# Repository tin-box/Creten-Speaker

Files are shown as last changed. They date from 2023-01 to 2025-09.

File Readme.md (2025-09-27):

<h1>Creten Bluetooth Speaker Project</h1>
<h2>Purpose</h2>
This is a fun project inspired by [DIY Perks] (https://www.youtube.com/@DIYPerks) on YouTube.  Instead of using carpentry, I elected to draw the project in CAD and 3D print the concrete form and most of the components.  I used PLA for the form and a high durometer TPU for speaker components. 
I also modified his design using a square port on the top to mount controls and other items vs his elongated port.  This change allows the concrete to flow into the space below the port more easily so that less water is required in the concrete mix which makes the housing stronger once cured.

This has been a fun hobby project and I hope sharing these 3D print STL files will allow other hobbyists to experiment and try out the appoach. 

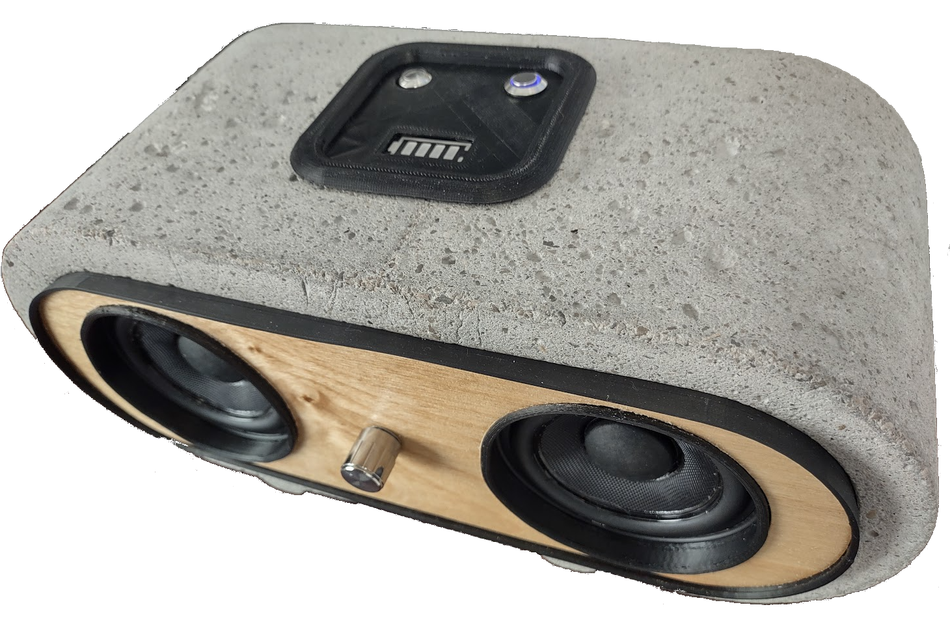
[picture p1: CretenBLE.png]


<h2>Instructions</h2>
The included STL models were created with Fusion360 using the free maker edition. 
The parts were all printed on a printer with 300mm x 300mm bed. 

The form built in halves, both to allow the final product to be larger than the printer bed allows as well as to make it so the form can be removed from the housing once the concrete has cured.
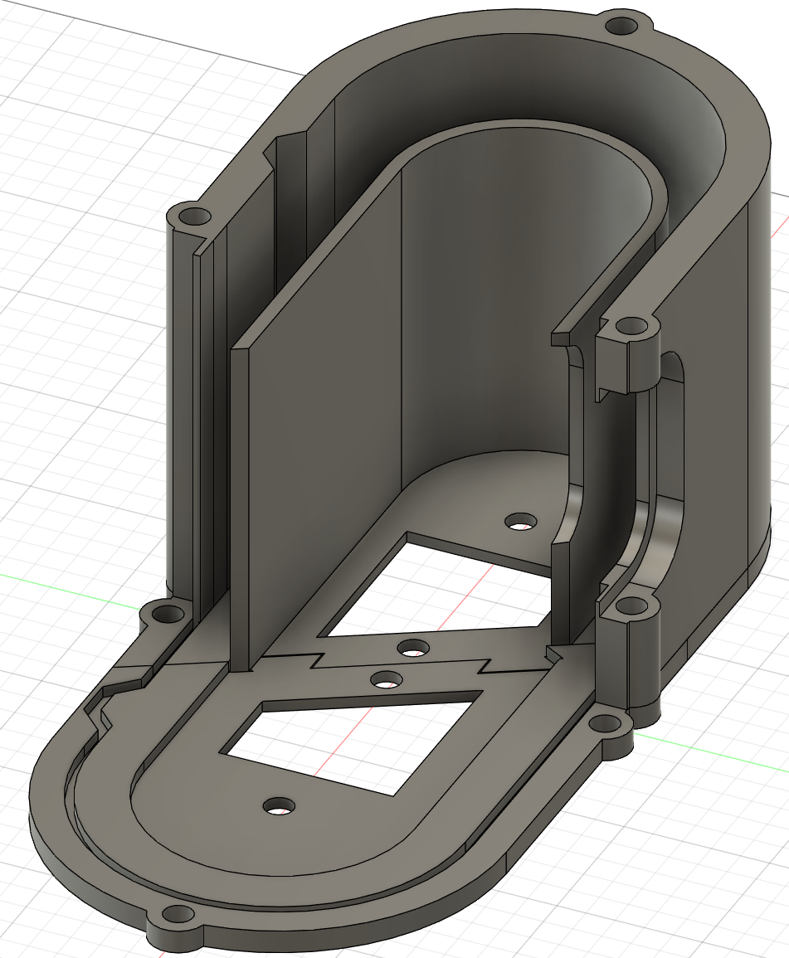
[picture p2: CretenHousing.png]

The Bottom Plate models are the first to print with the inner and outer shells mounting to the Bottom plates.  They all have a tongue and groove design that keeps everything from deforming with the weight of the concrete and also prevents the concrete from leaking, if you use vibration to remove air bubble from the mix.  

The Pins hold all of the forms together and allow the form to be dissassembled once the concreete cures. 

The Speaker mount, Speaker Rings, Control Panel and USB plug are all printed from TPU.  3" Dayton Audio speakers were purchased from Dayton Audio and 50W BLE amplifier board purchased on Amazon. 

<h2>Finishing</h2>
After the concrete cured I cleaned up the housing by sanding it with 80grit sand paper with a water slurry.  This cleaned up the edges and exposed the aggregate on the surfaces.  The Speaker mount assembly is a press fit.  There is a speaker mount pattern that I used to cut out a thin piece of plywood that give the front an warm accent and hides the speaker fasteners. The Speaker mount and speaker rings have a lip in the design that holds the wood insert.  Installing the wood insert is tight and requires a technique similar to mounting a tire on a rim.  

I used USB-C type charge port interface in the printed grommet.  This was connected to a Battery Management PCB board for a 3S or 4S configuration that is wired to an on/off switch and mattery level indicator.  There is a momentary switch type button in the battery level indicator circuit that power the level indicator when pressed.   I used Lithium Ion 13650 batteries from disassembled old laptop batteries.  in a 3 battery configuration it gives me 8 hours of runtime. 

I know the instructions are sparse, but its a hobby project you should modify the materials to your own design and have fun figuring it out.

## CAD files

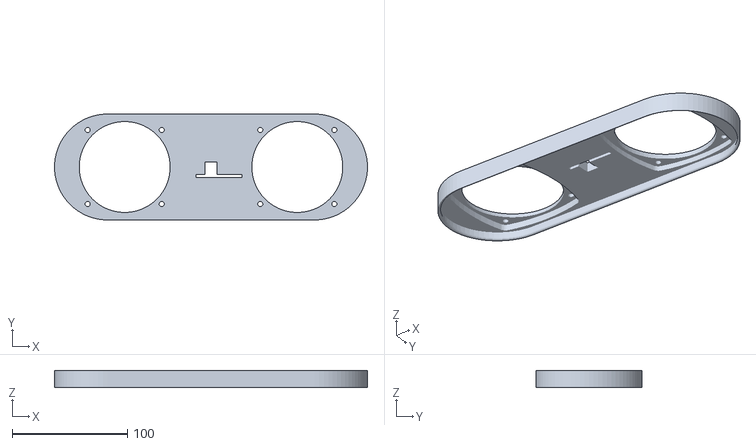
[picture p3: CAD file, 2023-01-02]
V4_3InchMountThin3mmV2.stl
272.0 x 92.0 x 15.0

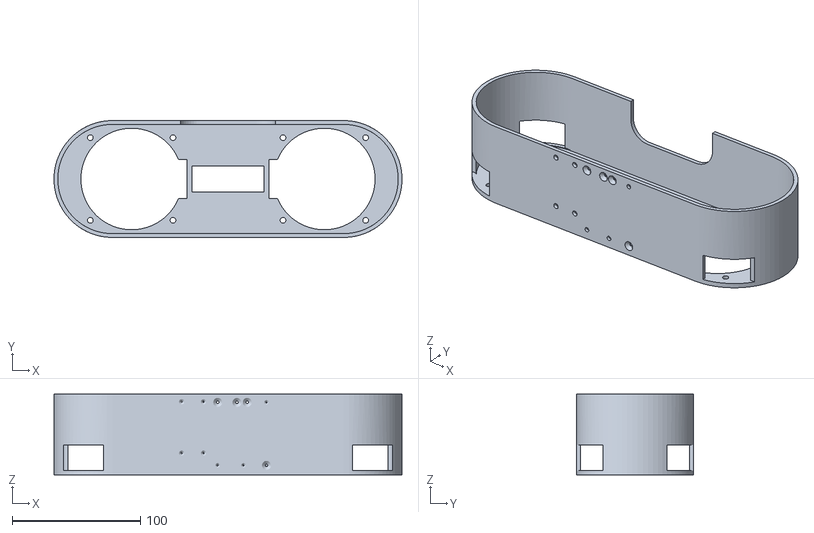
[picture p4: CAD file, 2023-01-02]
V4_MountSupportv2.stl
270.9 x 91.0 x 63.0

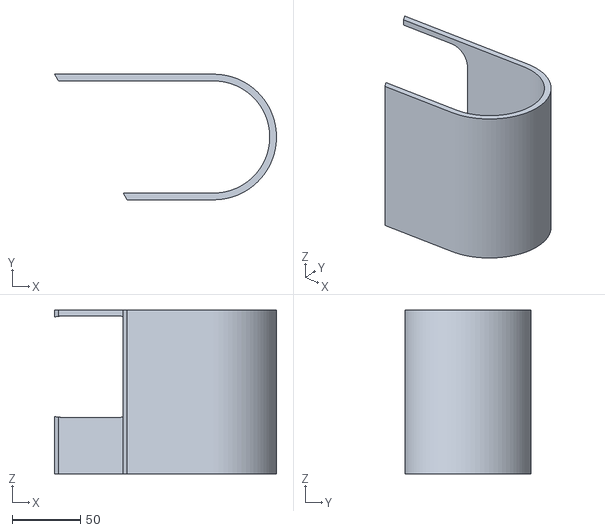
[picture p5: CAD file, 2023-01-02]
V4_InnerHalfNoBottom_R.stl
162.5 x 92.0 x 120.0

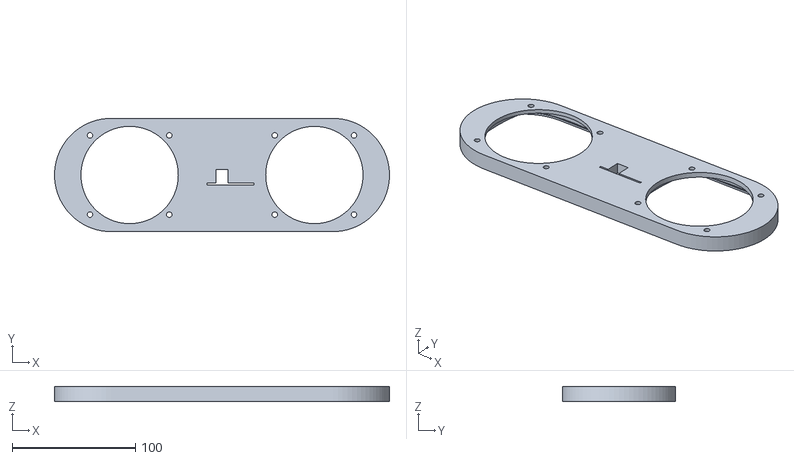
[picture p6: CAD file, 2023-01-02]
V4_3InchMountThin.stl
272.0 x 92.0 x 12.0

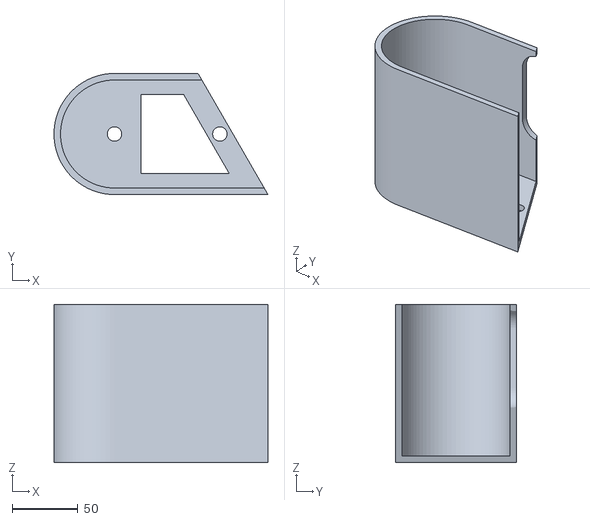
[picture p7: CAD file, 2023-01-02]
V4_InnerHalf_L.stl
162.5 x 92.0 x 120.0

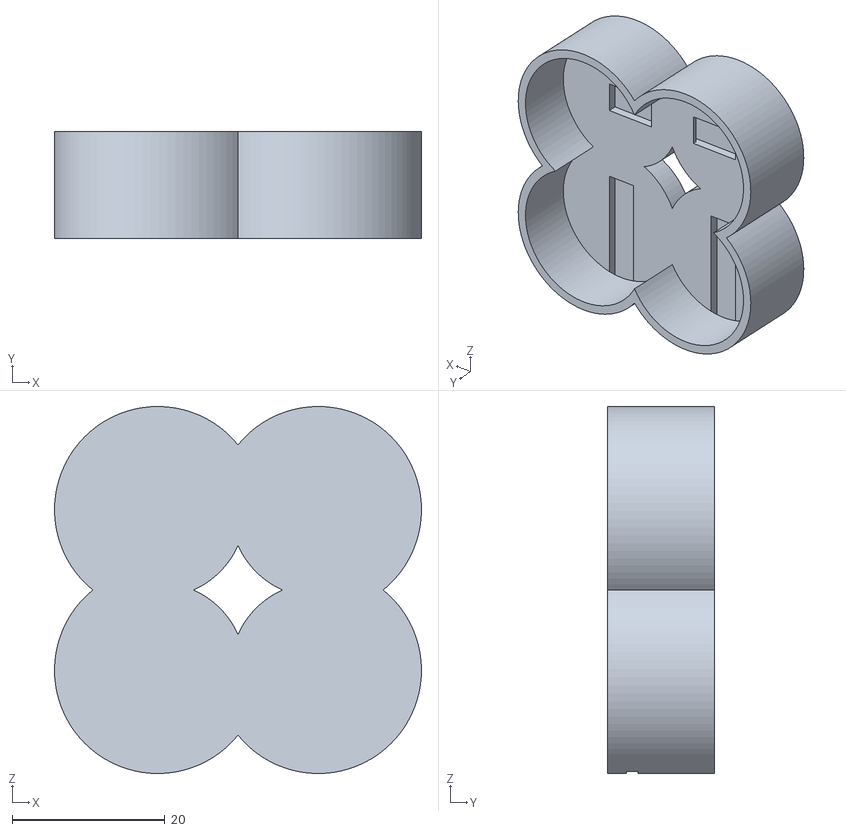
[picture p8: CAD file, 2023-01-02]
QuadBaseCap_Bridge.stl
48.0 x 14.0 x 48.0

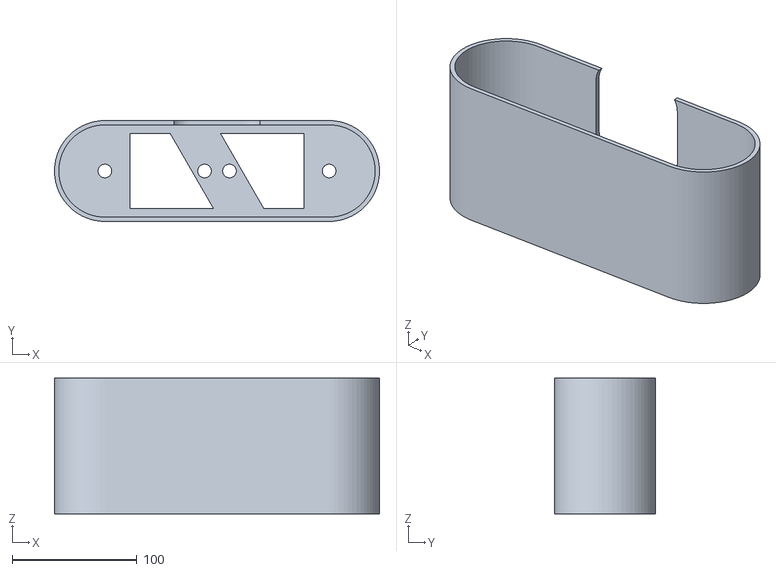
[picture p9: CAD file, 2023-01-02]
V4_LinerForNoBottom.stl
260.9 x 81.0 x 109.0

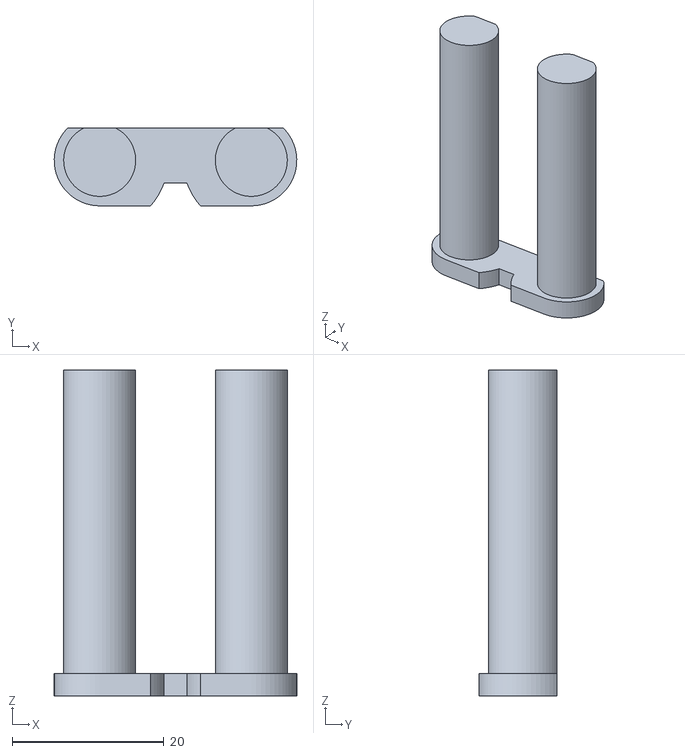
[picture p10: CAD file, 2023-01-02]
Bottom_Short_Pin.stl
32.0 x 10.2 x 43.0

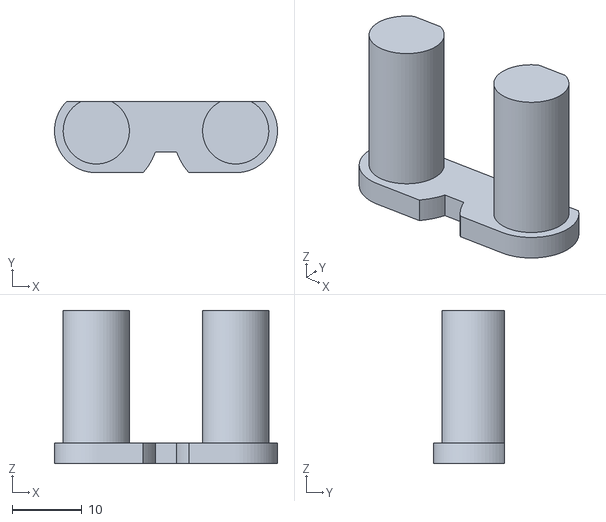
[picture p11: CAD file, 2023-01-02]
Top_Short_Pin.stl
32.0 x 10.2 x 22.0

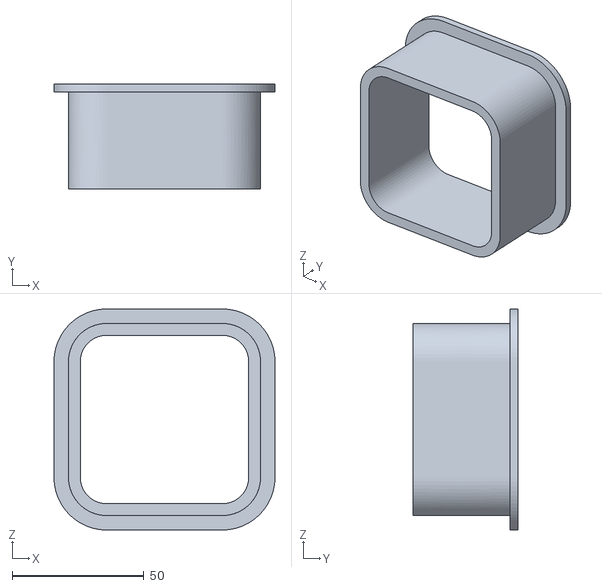
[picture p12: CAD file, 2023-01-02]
V4_Side.stl
84.0 x 40.0 x 84.0

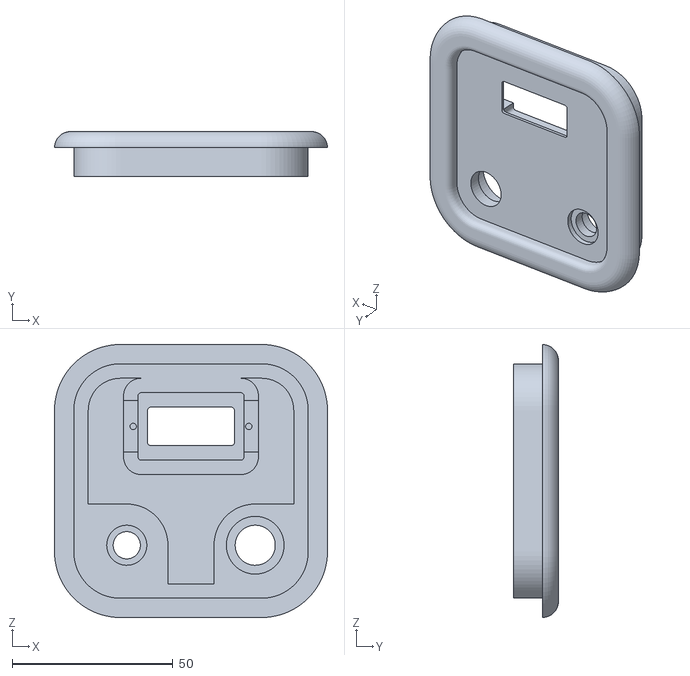
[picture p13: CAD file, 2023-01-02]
V4_QuadControlPanel_V5.stl
85.0 x 14.0 x 85.0

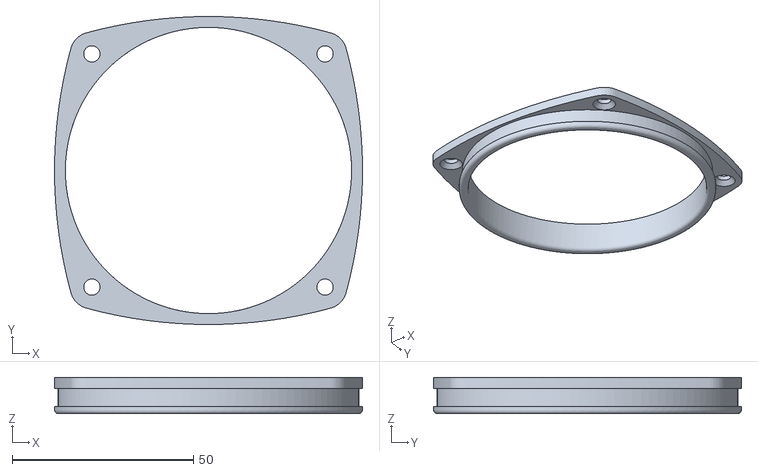
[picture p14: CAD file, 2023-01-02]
V4_3InchRing.stl
85.0 x 85.0 x 10.0

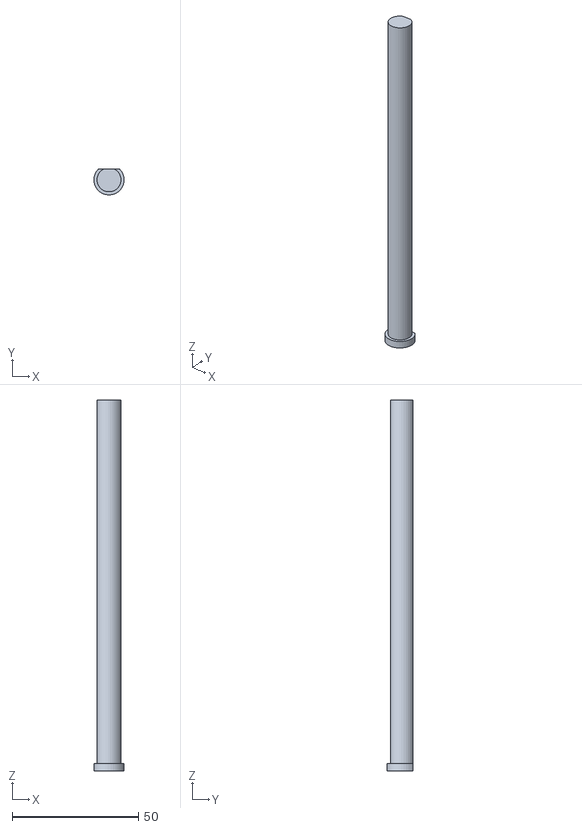
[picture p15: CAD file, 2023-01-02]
Long_Single_Pin.stl
12.0 x 10.2 x 147.0

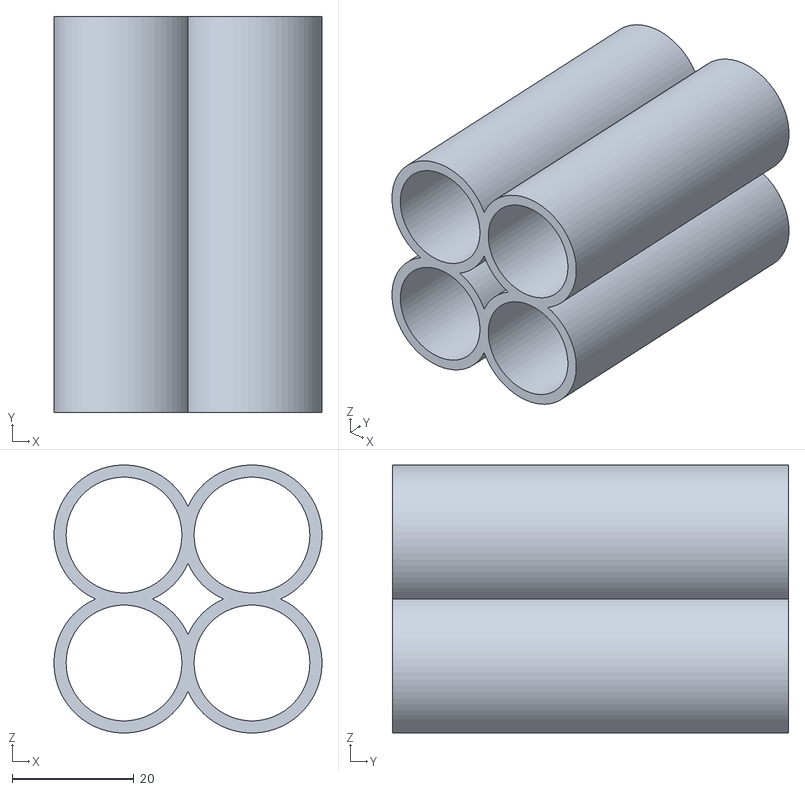
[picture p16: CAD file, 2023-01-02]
Quad18650Tube_OpenCenter.stl
44.0 x 65.0 x 44.0

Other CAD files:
V4_MountSupport.stl
V4_OuterShell_R.stl
V4_BottomPlate_L.stl
V4_QuadControlPanel_V4.stl
Long_Dual_Pin.stl
Quad18650Tube.stl
QuadBaseCap.stl
QuadControlPanel.stl
QuadControlPanelNoLamp.stl
QuadTopCap.stl
QuadTopCap_Bridge.stl
USB_Plug3.8mmdiameter.stl
V4Bolt.stl
V4Nut.stl
V4_3InchMount.stl
V4_3InchMountThin3mm.stl
V4_BottomPlate_R.stl
V4_InnerHalfNoBottom_L.stl
V4_InnerHalf_R.stl
V4_InnerTopPwr.stl
V4_Liner.stl
V4_OuterShell_L.stl
V4_PwrPlug.stl
V4_QuadControlPanel_V2.stl
V4_QuadControlPanel_V3.stl
V4_VolKnob.stl
V4_VolKnob6mm.stl
V4_WoodPattern.stl
